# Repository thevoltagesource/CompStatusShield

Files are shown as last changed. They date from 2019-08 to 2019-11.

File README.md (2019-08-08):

# Compressor Status PCB
## Wemos D1 Mini Shield to monitor the A/C control signals.

My A/C has a two stage compressor.  The system should run on stage 1 the majority of the time and run on stage 2 when the
themostat detects a temperture delta at or greater than the programmed value.  Unfortunatly the thermostat doesn't report
what stage is engaged, only that the system is cooling. More importantly, the thermostat will cool beyond the temperature 
set point to lower the humidity in the house but it does not report this state to the cloud service.  Since I want to 
track when the A/C is running I had to find a creative way of monitoring the system. And this little project came to be.

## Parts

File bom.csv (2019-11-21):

COMPRESSOR STATUS V1.1
Mouser # | Mfr. # | Manufacturer | Description | Order Qty. | Price (USD) | Ext.: (USD)
512-MID400S | MID400S | ON Semiconductor | Logic Output Optocouplers 8-Pin Optocoupler Logic aC Line | 2 | $3.90 | $7.80
845-29.003 | 29.003 | Altech | Fixed Terminal Blocks AK550/3wp PCB | 2 | $0.56 | $1.12
71-CRCW060310K0JNEAC | CRCW060310K0JNEAC | Vishay | Thick Film Resistors - SMD 1/10Watt 10Kohms 5% Commercial Use | 2 | $0.10 | $0.20
71-CRCW06031K00JNEAC | CRCW06031K00JNEAC | Vishay | Thick Film Resistors - SMD 1/10Watt 1Kohms 5% Commercial Use | 2 | $0.10 | $0.20
71-CRCW06034K70JNEAC | CRCW06034K70JNEAC | Vishay | Thick Film Resistors - SMD 1/10Watt 4.7Kohms 5% Commercial Use | 2 | $0.10 | $0.20
859-LTST-C191KRKT | LTST-C191KRKT | Lite-On | Standard LEDs - SMD Red Clear 631nm | 1 | $0.26 | $0.26
859-LTST-C190KFKT | LTST-C190KFKT | Lite-On | Standard LEDs - SMD Orange Clear 605nm | 1 | $0.23 | $0.23

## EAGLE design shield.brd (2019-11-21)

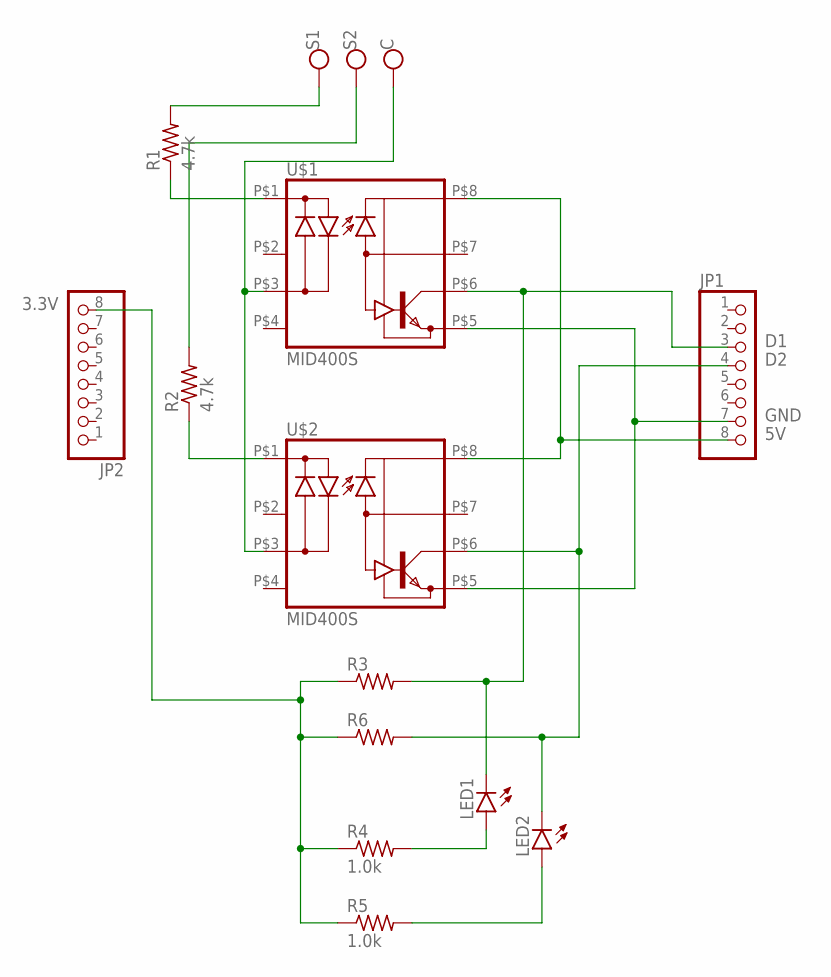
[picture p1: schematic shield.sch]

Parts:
JP1, JP2: PINHD-1X8/OCT; 1X08/OCT
LED1, LED2: LEDSML0603; SML0603
R1, R2: 4.7k; R0603
R3, R6: R-US_R0603; R0603
R4, R5: 1.0k; R0603
U$1, U$2: MID400S; SMT8
X1: AK550/3QUIET; AK550/3-N

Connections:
3.3V: JP2.8, R3.1, R4.1, R5.1, R6.1
5V: JP1.8, U$1.P$8 (VCC), U$2.P$8 (VCC)
C: U$1.P$3 (AC2), U$2.P$3 (AC2), X1.1
D1: JP1.3, LED1.C, R3.2, U$1.P$6 (VO)
D2: JP1.4, LED2.C, R6.2, U$2.P$6 (VO)
GND: JP1.7, U$1.P$5 (GND), U$2.P$5 (GND)
unnamed: R2.1, U$2.P$1 (AC1)
unnamed: R1.1, U$1.P$1 (AC1)
unnamed: LED2.A, R5.2
unnamed: LED1.A, R4.2
S1: R1.2, X1.3
S2: R2.2, X1.2

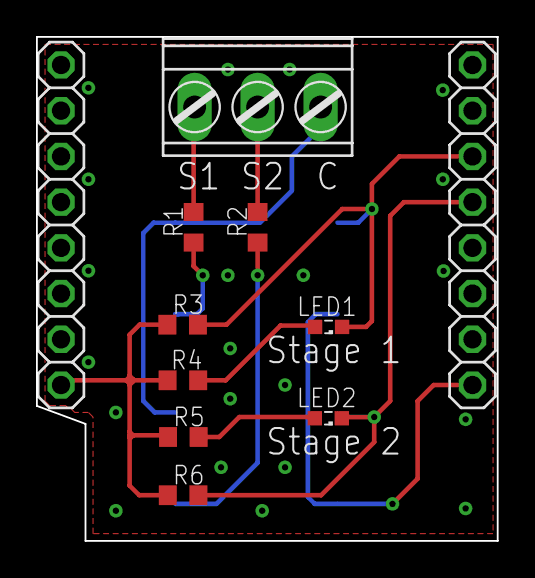
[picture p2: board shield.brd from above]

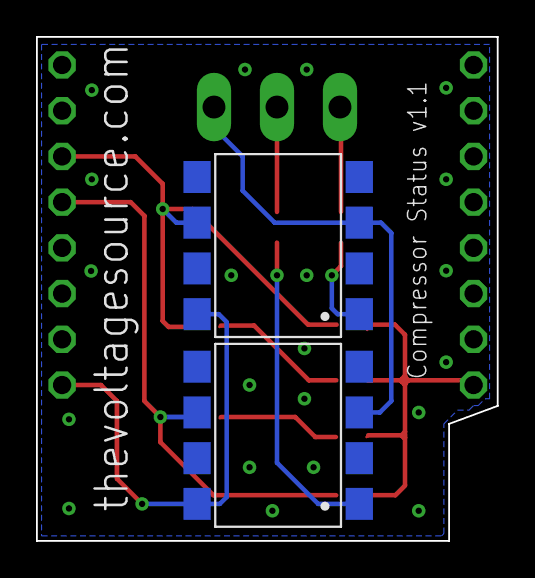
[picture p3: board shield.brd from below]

Board: 2 copper layers, 25.6 x 28.0 mm, 13 parts (2 on the bottom side), 12 nets.

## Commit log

2019-08-08 Version 1.0 as ordered from OSHPark
    [shield.brd, shield.sch]
2019-11-20 Parts list
    [bom.csv]
2019-11-21 board tweaks, bom fix, local library added
    [bom.csv, shield.brd, shield.sch]
